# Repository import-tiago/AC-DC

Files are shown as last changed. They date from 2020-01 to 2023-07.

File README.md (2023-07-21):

# AC-DC




AC-DC is a 240W linear bench power supply features two variable and independent 1.2V-24V and 5A outputs.

## Mounted Power Supply  
<p float="left">
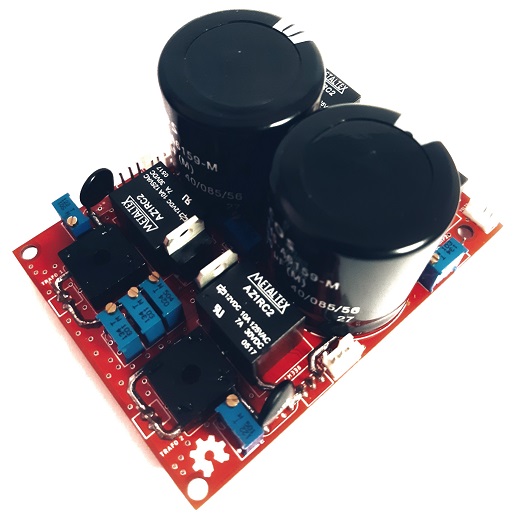
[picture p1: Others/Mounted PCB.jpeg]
  
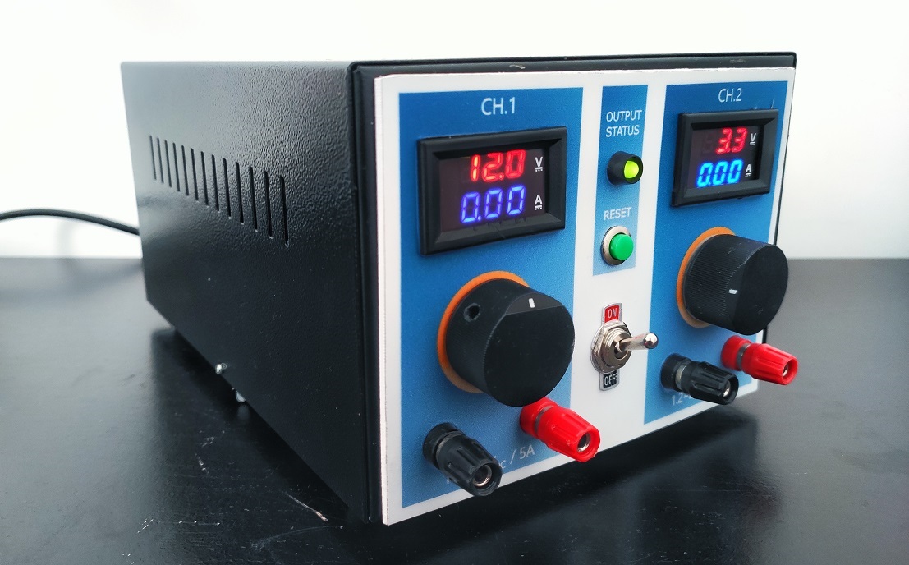
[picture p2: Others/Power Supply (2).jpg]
  
</p>

## Gerber Preview
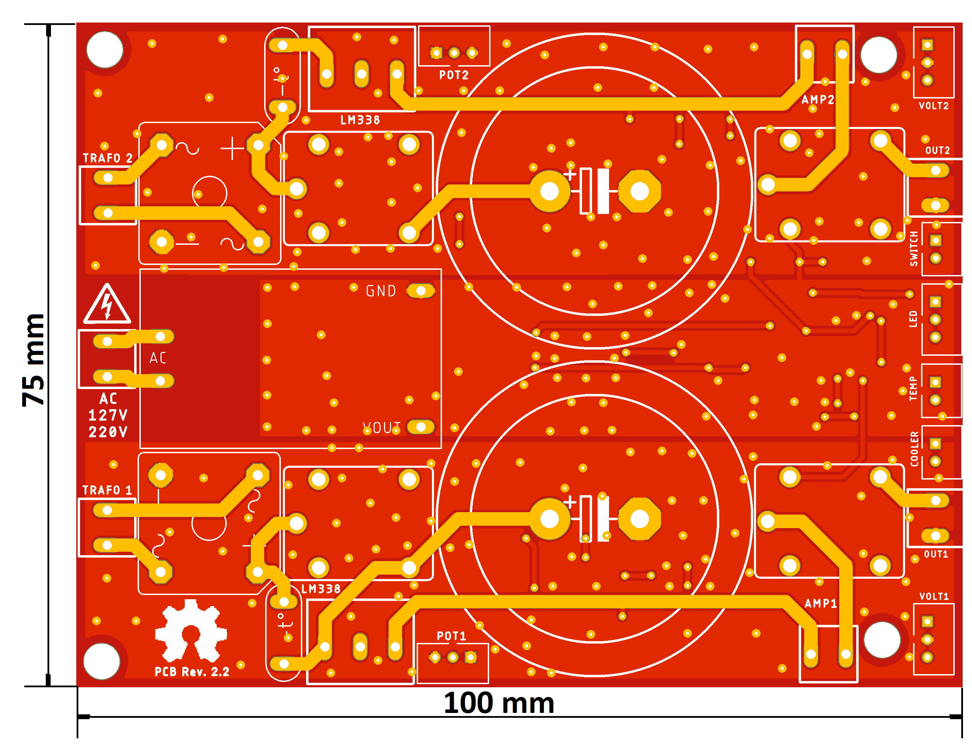
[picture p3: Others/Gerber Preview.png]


## Schematic
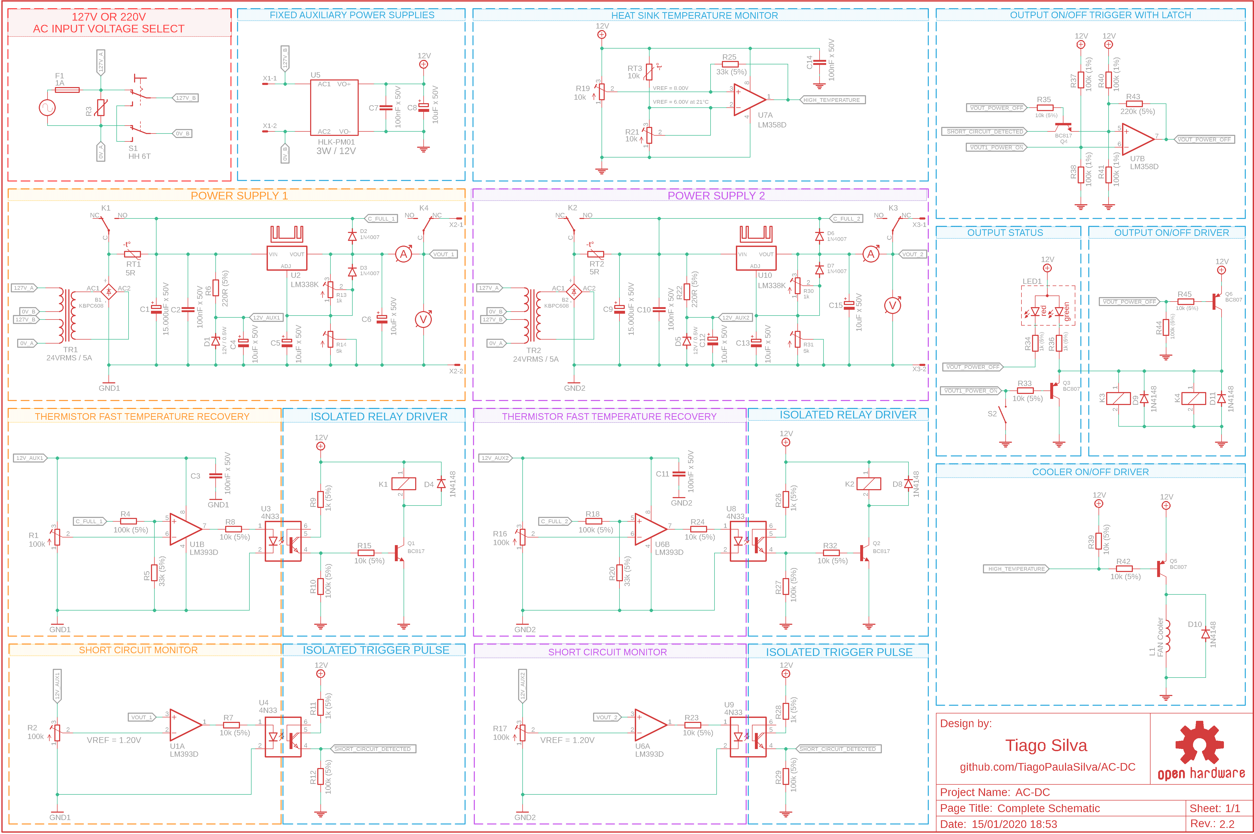
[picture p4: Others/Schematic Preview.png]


### Contributing
0. Give this project a :star:
1. Create an issue and describe your idea.
2. [Fork it](https://github.com/import-tiago/AC-DC/fork).
3. Create your feature branch (`git checkout -b my-new-feature`).
4. Commit your changes (`git commit -a -m "Added feature title"`).
5. Publish the branch (`git push origin my-new-feature`).
6. Create a new pull request.
7. Done! :heavy_check_mark:

### License Information
<br /><span xmlns:dct="http://purl.org/dc/terms/" property="dct:title">AC-DC</span> by <a xmlns:cc="http://creativecommons.org/ns#" href="https://github.com/import-tiago" property="cc:attributionName" rel="cc:attributionURL">Tiago Silva</a> is licensed under a <a rel="license" href="http://creativecommons.org/licenses/by-sa/4.0/">Creative Commons Attribution-ShareAlike 4.0 International License</a>.<br />Permissions beyond the scope of this license may be available at <a xmlns:cc="http://creativecommons.org/ns#" href="https://twitter.com/import_tiago" rel="cc:morePermissions">tiagodepaulasilva@gmail.com</a>.

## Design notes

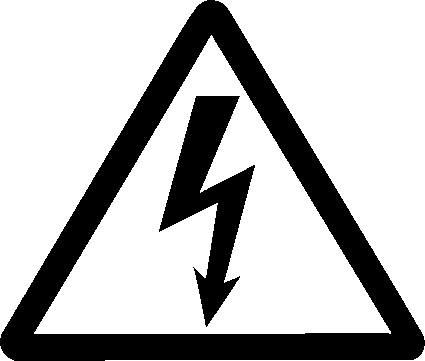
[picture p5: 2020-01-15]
Hardware/4. Others/High Voltage Symbol.bmp

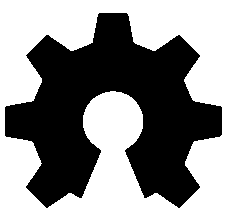
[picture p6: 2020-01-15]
Hardware/4. Others/Open Hardware Symbol.bmp

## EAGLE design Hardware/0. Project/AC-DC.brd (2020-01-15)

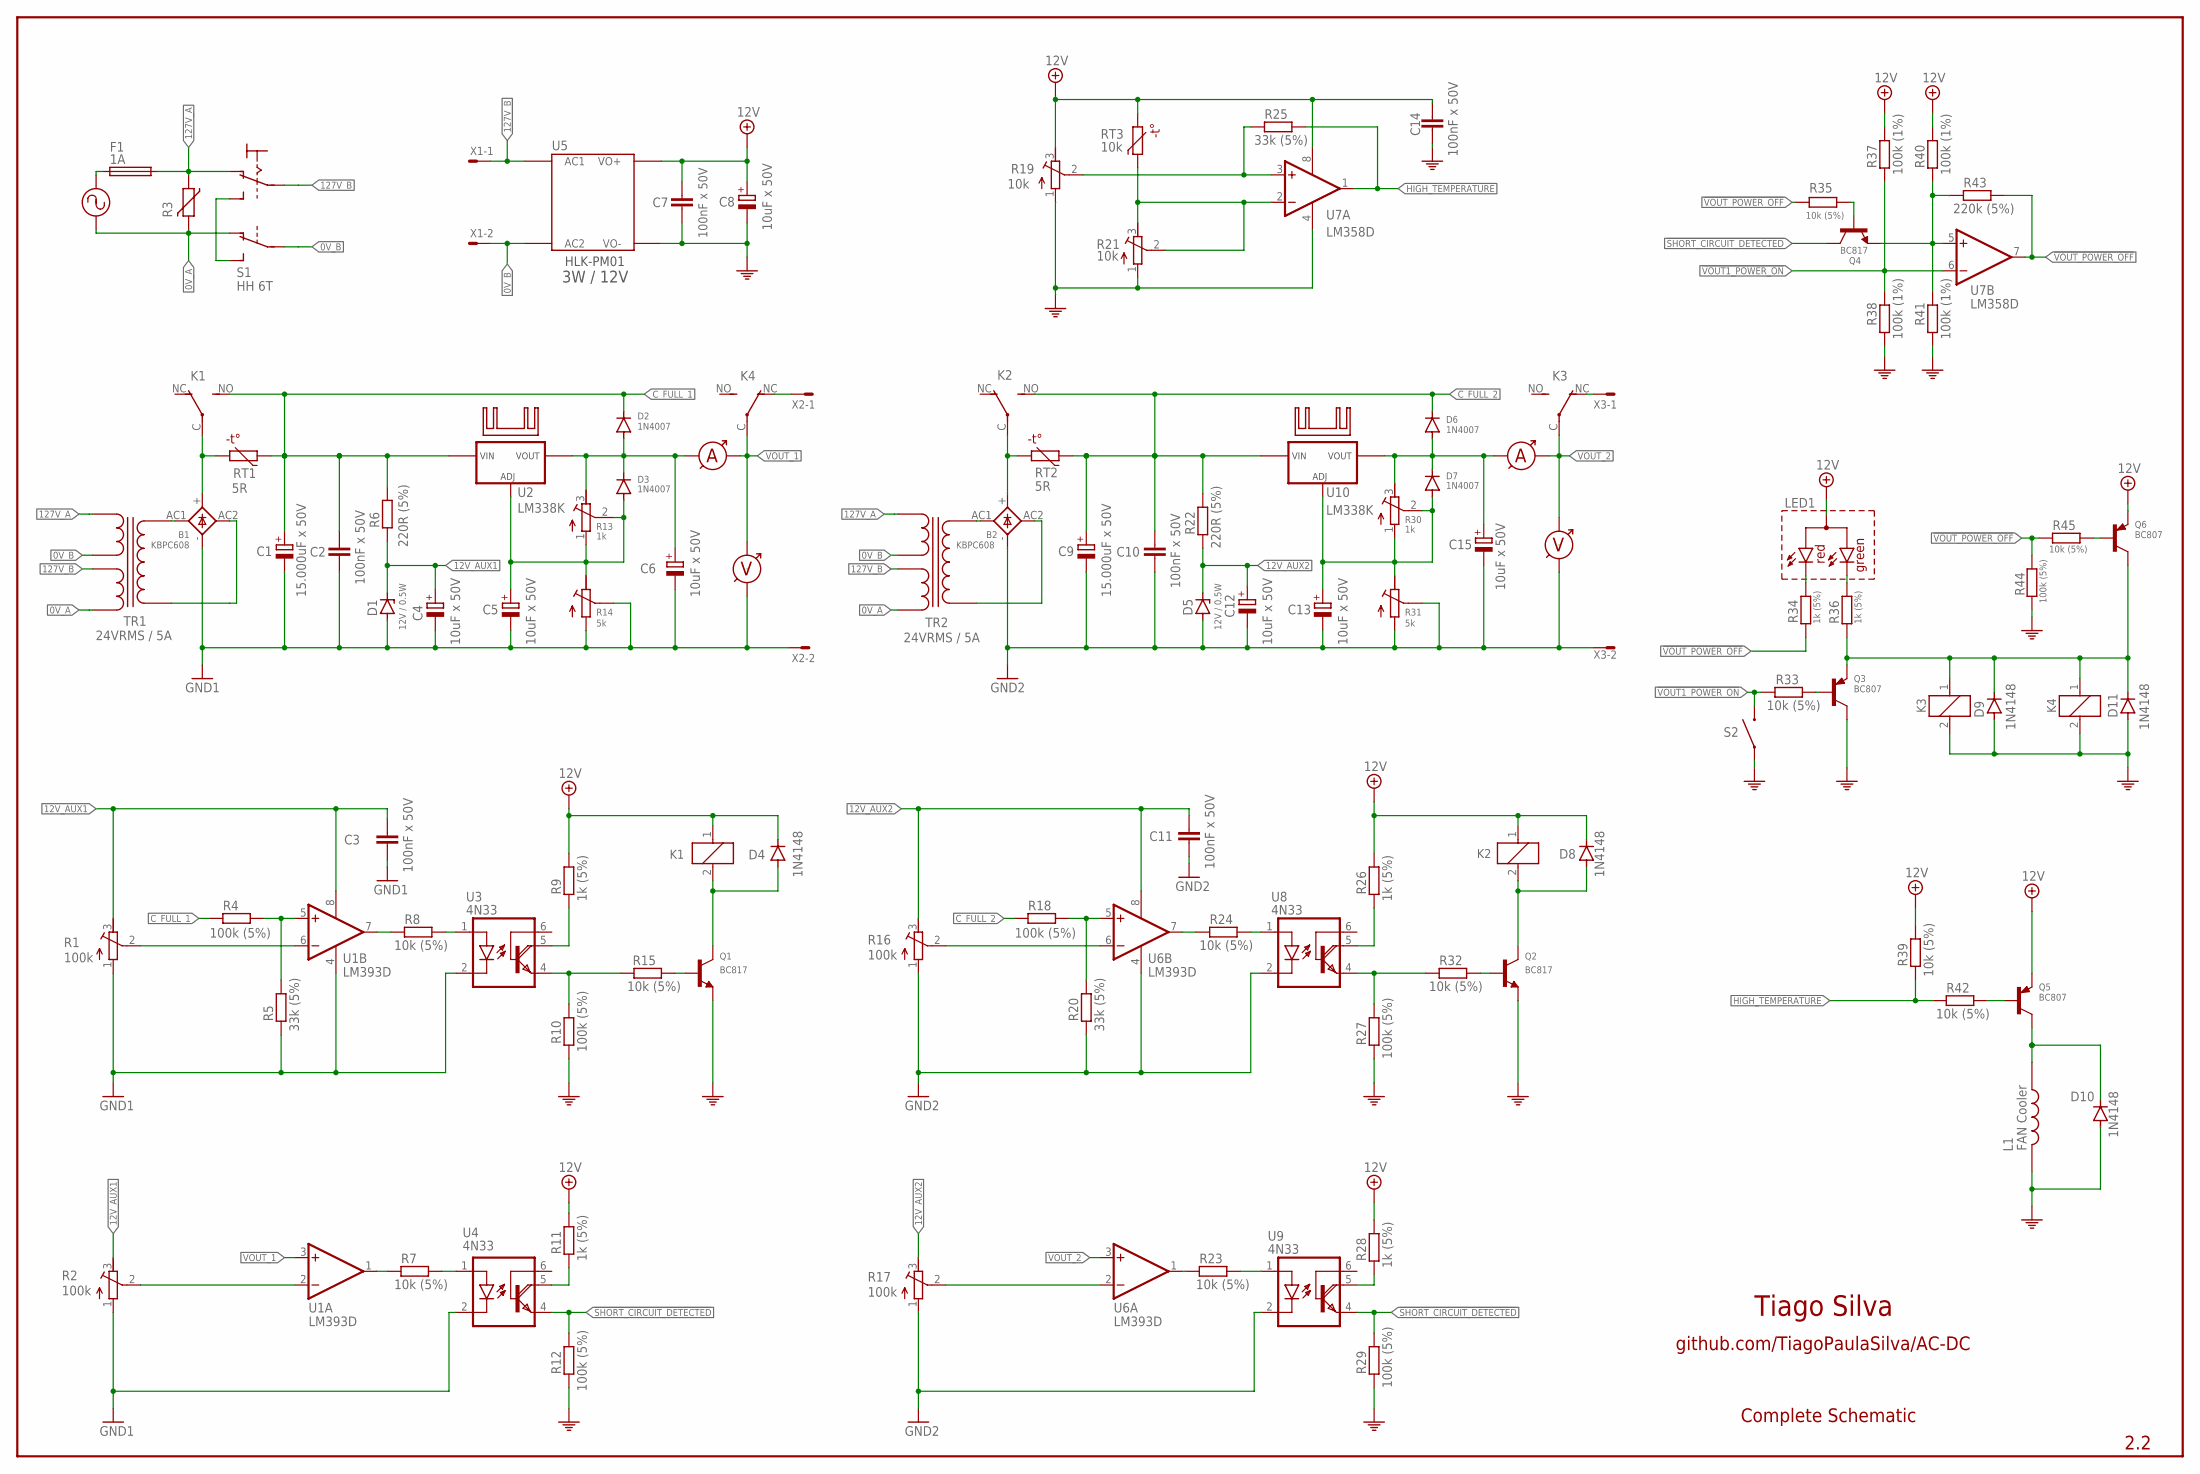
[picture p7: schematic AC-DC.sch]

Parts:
AMP1, AMP2: AMMETER
B1, B2: KBPC608; GBPC1
C1, C9: 15.000uF x 50V; EB35D
C2, C3, C7, C10, C11, C14: 100nF x 50V; C0805
C4, C5, C6, C8, C12, C13, C15: 10uF x 50V; 153CLV-0605
D1, D5: 12V / 0.5W; SOD80C
D2, D3, D6, D7: 1N4007; SOD-123_MINI-SMA
D4, D8, D9, D10, D11: 1N4148; SOD80C
K1, K2, K3, K4: CQ1-12V; CQ1
L1: FAN Cooler; MOLEX-2P
LED1: LED-BICOLOR-MOLEX3P; MOLEX3P
Q1, Q2, Q4: BC817; SOT23
Q3, Q5, Q6: BC807; SOT23-BEC
R1, R2, R16, R17: 100k; RTRIM3202
R4, R10, R12, R18, R27, R29, R44: 100k (5%); R0805
R5, R20, R25: 33k (5%); R0805
R6, R22: 220R (5%); R2512
R7, R8, R15, R23, R24, R32, R33, R35, R39, R42, R45: 10k (5%); R0805
R9, R11, R26, R28, R34, R36: 1k (5%); R0805
R13, R30: 1k; RTRIM3202
R14, R31: 5k; MOLEX3P
R19, R21: 10k; RTRIM3202
R37, R38, R40, R41: 100k (1%); R0805
R43: 220k (5%); R0805
RT1, RT2: 5R; 11MM
RT3: 10k; MOLEX2P
S2: SWITCH-MOLEX2P; MOLEX-2P
TR1, TR2: 24VRMS / 5A; 2PINS
U1, U6: LM393D; SO08
U2, U10: LM338K; MOLEX3P
U3, U4, U8, U9: 4N33; DIL6-SMD
U5: HLK-PM01
U7: LM358D; SO08
VOLT1, VOLT2: VOLTMETER
X1, X2, X3: 22-23-2021

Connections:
0V_B: U5.P$2 (AC2), X1.2
12V_AUX1: C3.1, C4.+, D1.C, R1.3 (E), R2.3 (E), R6.1, U1.8 (V+), VOLT1.P$1
12V_AUX2: C11.1, C12.+, D5.C, R16.3 (E), R17.3 (E), R22.1, U6.8 (V+), VOLT2.P$1
127V_B: U5.P$1 (AC1), X1.1
!SHORT_CIRCUIT_DETECTED!: Q4.3 (C), R12.2, R29.2, U4.4 (E), U9.4 (E)
!VOUT1_POWER_ON!: R33.2, R37.1, R38.2, S2.P$2 (2), U7.6 (-IN)
!VOUT1_POWER_ON!1: R11.1, U4.5 (COL)
!VOUT1_POWER_ON!2: R9.1, U3.5 (COL)
!VOUT1_POWER_ON!3: R28.1, U9.5 (COL)
!VOUT1_POWER_ON!4: R26.1, U8.5 (COL)
!VOUT_POWER_OFF!: R34.2, R35.1, R43.2, R44.1, R45.1, U7.7 (OUT)
+12V: C7.1, C8.+, C14.1, D4.C, D8.C, K1.1, K2.1, LED1.P$1 (A), Q5.E, Q6.E, R9.2, R11.2, R19.3 (E), R26.2, R28.2, R37.2, R39.2, R40.2, RT3.P$2 (2), U5.P$4 (VO+), U7.8 (V+)
C_FULL_1: C1.+, C2.1, D2.C, K1.NO (S), R4.2, R6.2, RT1.P$1 (1), U2.1 (VIN)
C_FULL_2: C9.+, C10.1, D6.C, K2.NO (S), R18.2, R22.2, RT2.P$1 (1), U10.1 (VIN)
GND1: B1.-, C1.-, C2.2, C3.2, C4.-, C5.-, C6.-, D1.A, R1.1 (A), R2.1 (A), R5.1, R14.P$1 (A), R14.P$3 (S), U1.4 (V-), U3.2 (C), U4.2 (C), VOLT1.P$2, X2.2
GND2: B2.-, C9.-, C10.2, C11.2, C12.-, C13.-, C15.-, D5.A, R16.1 (A), R17.1 (A), R20.1, R31.P$1 (A), R31.P$3 (S), U6.4 (V-), U8.2 (C), U9.2 (C), VOLT2.P$2, X3.2
HIGH_TEMPERATURE: R25.2, R39.1, R42.1, U7.1 (OUT)
unnamed: B1.+, K1.C, RT1.P$2 (2)
unnamed: D4.A, K1.2, Q1.3 (C)
unnamed: LED1.P$3 (CR), R34.1
unnamed: Q1.1 (B), R15.2
unnamed: R17.2 (S), U6.2 (-IN)
unnamed: R1.2 (S), U1.6 (-IN)
unnamed: Q6.B, R45.2
unnamed: B1.AC1, TR1.1
unnamed: B1.AC2, TR1.2
unnamed: D9.C, D11.C, K3.1, K4.1, Q3.E, Q6.C, R36.1
unnamed: LED1.P$2 (CG), R36.2
unnamed: Q3.B, R33.1
unnamed: AMP1.2, C6.+, D2.A, D3.C, R13.3 (E), U2.3 (VOUT)
unnamed: C5.+, D3.A, R13.1 (A), R13.2 (S), R14.P$2 (E), U2.2 (GND)
unnamed: K4.NC (O), X2.1
unnamed: R4.1, R5.2, U1.5 (+IN)
unnamed: R7.1, U1.1 (OUT)
unnamed: R7.2, U4.1 (A)
unnamed: Q4.2 (E), R40.1, R41.2, R43.1, U7.5 (+IN)
unnamed: Q4.1 (B), R35.2
unnamed: B2.AC1, TR2.1
unnamed: B2.AC2, TR2.2
unnamed: R2.2 (S), U1.2 (-IN)
unnamed: AMP2.2, C15.+, D6.A, D7.C, R30.3 (E), U10.3 (VOUT)
unnamed: C13.+, D7.A, R30.1 (A), R30.2 (S), R31.P$2 (E), U10.2 (GND)
unnamed: K3.NC (O), X3.1
unnamed: B2.+, K2.C, RT2.P$2 (2)
unnamed: Q5.B, R42.2
unnamed: D8.A, K2.2, Q2.3 (C)
unnamed: R21.2 (S), R21.3 (E), RT3.P$1 (1), U7.2 (-IN)
unnamed: R19.2 (S), R25.1, U7.3 (+IN)
unnamed: R8.1, U1.7 (OUT)
unnamed: D10.C, L1.P$1 (1), Q5.C
unnamed: R8.2, U3.1 (A)
unnamed: Q2.1 (B), R32.2
unnamed: R18.1, R20.2, U6.5 (+IN)
unnamed: R23.1, U6.1 (OUT)
unnamed: R16.2 (S), U6.6 (-IN)
unnamed: R23.2, U9.1 (A)
unnamed: R24.1, U6.7 (OUT)
unnamed: R24.2, U8.1 (A)
unnamed: R27.2, R32.1, U8.4 (E)
unnamed: R10.2, R15.1, U3.4 (E)
PE: C7.2, C8.-, C14.2, D9.A, D10.A, D11.A, K3.2, K4.2, L1.P$2 (2), Q1.2 (E), Q2.2 (E), Q3.C, R10.1, R12.1, R19.1 (A), R21.1 (A), R27.1, R29.1, R38.1, R41.1, R44.2, S2.P$1 (1), U5.P$3 (VO-), U7.4 (V-)
VOUT_1: AMP1.1, K4.C, U1.3 (+IN), VOLT1.P$3
VOUT_2: AMP2.1, K3.C, U6.3 (+IN), VOLT2.P$3

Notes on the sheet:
Tiago Silva
github.com/TiagoPaulaSilva/AC-DC
2.2
Complete Schematic
3W / 12V

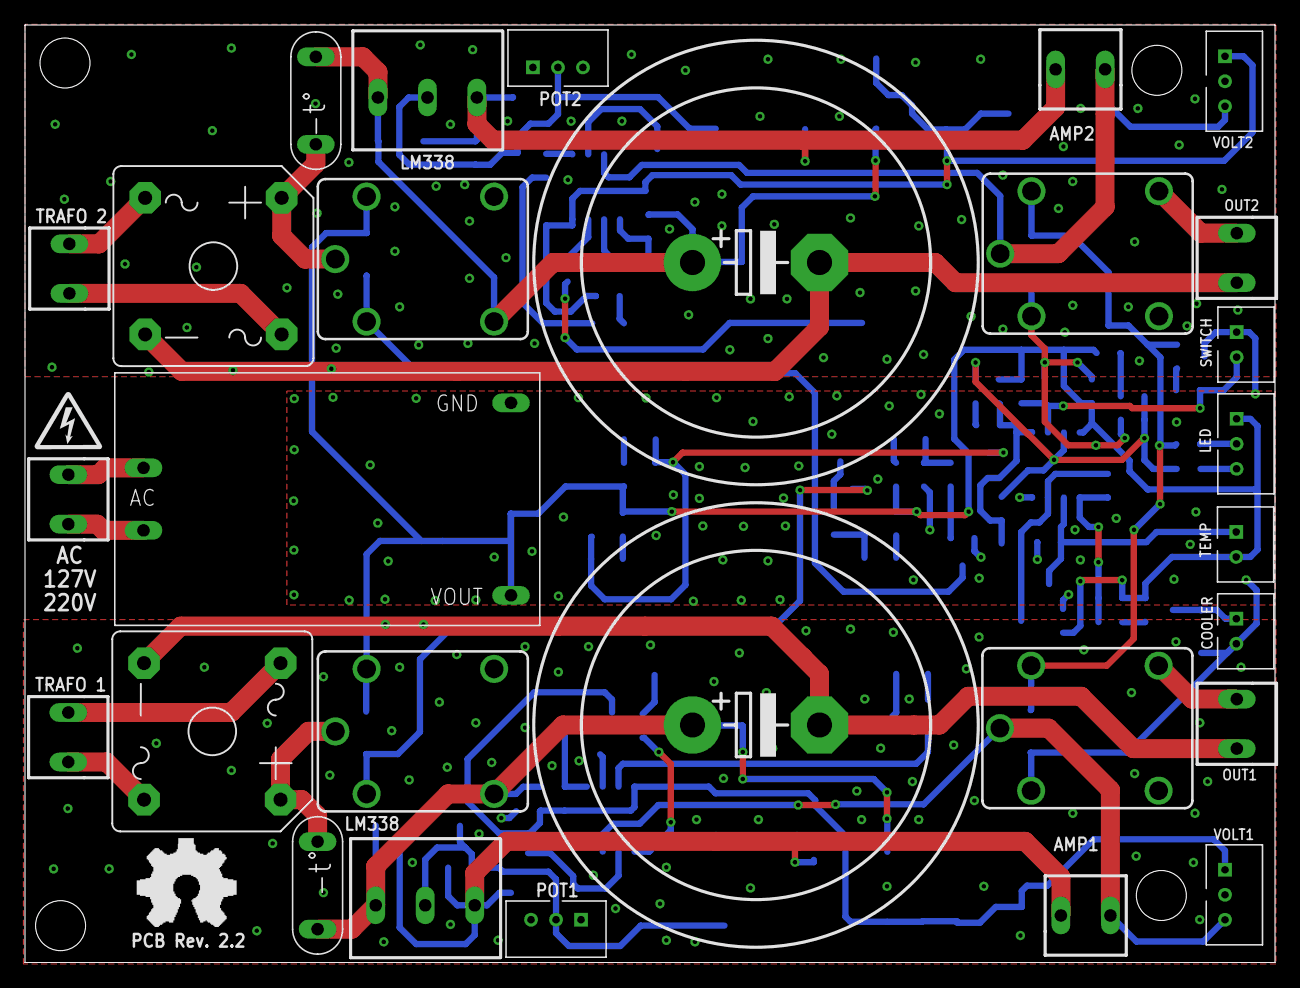
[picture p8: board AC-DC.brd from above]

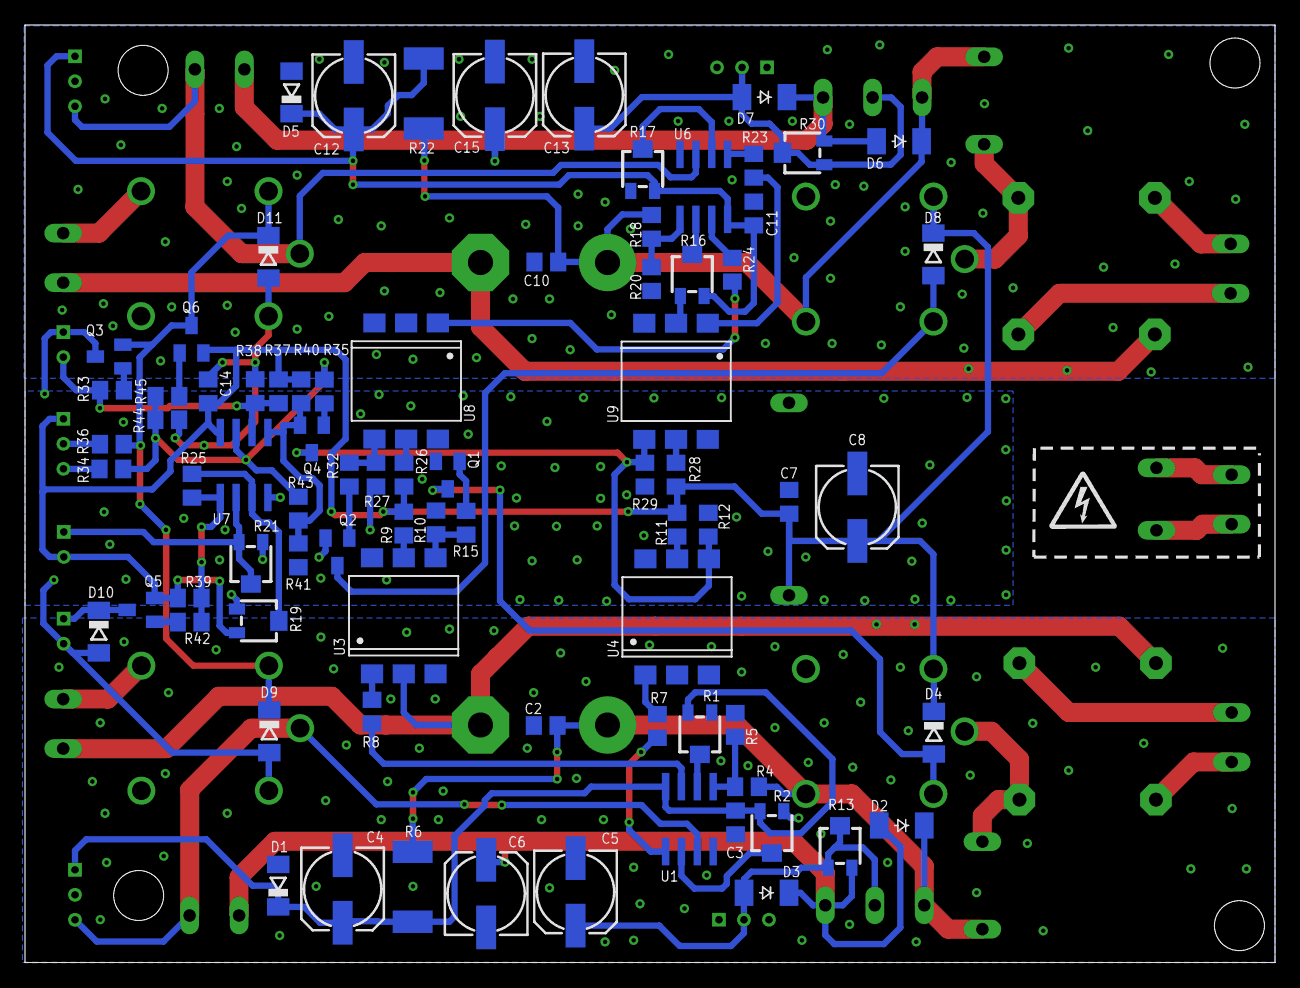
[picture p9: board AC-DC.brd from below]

Board: 2 copper layers, 100.0 x 75.0 mm, 107 parts (79 on the bottom side), 63 nets.

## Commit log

2019-08-01 Schematic created
    [AC-DC.sch]
2019-08-02 Schematic design started
    [AC-DC.sch]
2019-08-02 Short-circuit added to schematic
    [AC-DC.sch, Short.DSN]
2019-08-03 Schematic done
    [AC-DC.sch, Short.DSN]
2019-08-04 Inrush current's capacitor circuit protect added
    [AC-DC.sch]
2019-08-04 Temperature Sensor for Heat Sink Added
    [AC-DC.sch]
2019-08-08 Minor improvements
    [AC-DC.sch]
2019-08-19 Schematic updated to 1.1 version
    [AC-DC.sch]
2019-08-20 PCB layout started
    [AC-DC.brd]
2019-08-21 PCB layout done
    [AC-DC.brd, AC-DC.sch]
2019-08-21 Gerber files generated
2019-08-21 tStop added to high current traces
    [AC-DC.brd]
2019-08-21 Hidden components names/values of silkscreen
    [AC-DC.brd]
2019-08-21 GND high current return improved
    [AC-DC.brd]
2019-08-21 Components designators repositioned
    [AC-DC.brd]
2019-11-29 Schematic updated to 2.0
    - All Op. Amps. that was voltage compators was updated to LM393.
    - Fixed conflicts at +12V and +24V lines.
    - Now, there is only one temperature circuit monitor.
    - Ground from supply1 and supply2 is now isolated from each other
    (series and parallel association are now possible).
    [AC-DC.brd, AC-DC.sch]
2019-12-04 Schematic 2.0 done
    [AC-DC.brd, AC-DC.sch]
2019-12-04 Schematic image from 2.0 added
2019-12-04 Schematic 2.1 (better organization)
    [AC-DC.brd, AC-DC.sch]
2019-12-16 Working on at 2.1 schematic
    [AC-DC.brd, AC-DC.sch]
2019-12-16 Relay datasheet added
2020-01-15 Schematic and PCB layout 2.1 updated
    [AC-DC.brd, AC-DC.sch]
2020-01-15 Gerber files from PCB 2.2
2020-01-15 Images used at PCB
2020-01-15 Gerber preview from 2.2 PCB layout
2020-01-15 PCB version ref added at PCB design
    [AC-DC.brd]
2020-01-15 File updated to 2.2 PCB rev.
    [AC-DC.brd, AC-DC.sch]
